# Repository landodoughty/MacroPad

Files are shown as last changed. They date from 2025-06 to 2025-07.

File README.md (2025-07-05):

# MacroPad
A Custom Macro Pad I Designed and Built based on the RP2040

# Features:
* Programmable keys allow shortcuts, macros, or controls to be customized.
* Hotswappable MX switches allows you to customize your typing feel.
* RGB Backlighting allows per-key lighting using WS2812/NeoPixel LEDs
* Custom 3d printed case provides a sleek, ergonomic look.

# Building the MacroPad

**The PCB:**
In this repository you can find the raw PCB files and the Gerber files which can allow you to manufacture the PCB through a service such as PCBWay or JLCPCB. I have also attached a BOM containing all the parts for the PCB. Most of the parts utilized on the PCB are very standard, and if you are assembling through JLCPCB the BOM already contains LCSC part numbers for most items. The only items which don't have part numbers, because I did not have them assembled through JLCPCB are the USB Micro-B connector, the reverse mount neopixel LEDs, the MX keyswitch sockets, and a small two pin 2.54mm pitch connector. The USB connector and the two pin connector can be easily bought from many places or even salvaged from old electronics. The [reverse mount LEDs]([url](https://www.adafruit.com/product/4960)) and [MX keyswitch sockets]([url](https://www.adafruit.com/product/4958)) are from adafruit. 

**Switches:**
You can use any MX compatible switches with the PCB, but keep in mind that they all have varying heights. The STLs provided are designed for switches with a 7mm above-board height with DSA keycaps, significantly less than most switches. If you want to use a different heigh you will likely have to adjust the STEP file provided to match your keyheight.

**Code:**
The code is provided but you will need to adjust it to fit your desires. This includes changing the LED modes and key press actions. Currently, the LED modes includes a constant color mode, an RGB mode, and a layer specific mode. To change layers, you press the first two buttons on the top row and then press the third button. To change colors in the constant color mode, you again press the first two buttons on the top row but then press the fourth button to change colors. To change the actions, scroll down to find the section where they are defined. The code shows how to do shortcuts, go to links, make a number pad, and how to create a shift key for a layer. To upload the code for the first time, short the two pins in the 2.54mm connector and then plug the MacroPad in through USB. It should pop up as detected and then yo ucan unshort the pins. Once you have done this once, you should be able to upload just with USB but if you are having issues uploading you may need to repeat the process.

**The Case:**
The case is 3d printed and I have provided both STL and STEP files for your conveinance. This means you can easily customize the case to your liking. The case needs 2 M3 heat set inserts, 2 M3 washers, and 2 M3 x 6 screws to assemble.

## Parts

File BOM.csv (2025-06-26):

Designator | Comment | Datasheet | Footprint | LCSC Part Number | Qty | DNP
C1,C2 | 15p | ~ | Capacitor_SMD:C_0603_1608Metric | C1644 | 2
C3,C4,C17 | 10u | ~ | Capacitor_SMD:C_0805_2012Metric | C15850 | 3
C5,C6,C7,C9,C11,C12,C13,C14,C15,C16 | 100n | ~ | Capacitor_SMD:C_0402_1005Metric | C1525 | 10
C8,C10 | 1u | ~ | Capacitor_SMD:C_0402_1005Metric | C52923 | 2
C21,C22,C23,C24,C25,C26,C27,C28,C29,C30,C31,C32,C33,C34,C35,C36,C37,C38,C39,C40 | 0.1u | ~ | Capacitor_SMD:C_0402_1005Metric | C1525 | 20
D1,D2,D3,D4,D5,D6,D7,D8,D9,D10,D11,D12,D13,D14,D15,D16,D17,D18,D19,D20 | NeoPixel_THT | https://www.adafruit.com/product/1938 | neoPixel:NEO3535_REVERSECorrected |  | 20
D21,D22,D23,D24,D25,D26,D27,D28,D29,D30,D31,D32,D33,D34,D35,D36,D37,D38,D39,D40 | 1N4148WS | https://www.vishay.com/docs/85751/1n4148ws.pdf | Diode_SMD:D_SOD-323 | C2128 | 20
H1,H2,H3,H4 | MountingHole | ~ | MountingHole:MountingHole_3.2mm_M3_ISO14580_Pad |  | 4
J1 | USB_B_Micro | ~ | Connector_USB:USB_Micro-B_Amphenol_10103594-0001LF_Horizontal | C10418 | 1
J2 | Conn_01x02 | ~ | Connector_PinHeader_2.54mm:PinHeader_1x02_P2.54mm_Vertical |  | 1
R1,R3 | 1k | ~ | Resistor_SMD:R_0402_1005Metric | C11702 | 2
R2 | DNF | ~ | Resistor_SMD:R_0402_1005Metric |  | 1
R4,R5 | 27 | ~ | Resistor_SMD:R_0402_1005Metric | C25100 | 2
SW1,SW2,SW3,SW4,SW5,SW6,SW7,SW8,SW9,SW10,SW11,SW12,SW13,SW14,SW15,SW16,SW17,SW18,SW19,SW20 | SW_SPST | ~ | keyswitches:Kailh_socket_MX |  | 20
U1 | AMS1117-3.3SOT223 | http://www.advanced-monolithic.com/pdf/ds1117.pdf | Package_TO_SOT_SMD:SOT-223 | C6186 | 1
U2 | W25Q128JVS | http://www.winbond.com/resource-files/w25q128jv_dtr%20revc%2003272018%20plus.pdf | Package_SO:SOIC-8_5.23x5.23mm_P1.27mm | C97521 | 1
U3 | RP2040 |  | Package_DFN_QFN:QFN-56-1EP_7x7mm_P0.4mm_EP3.2x3.2mm | C2040 | 1
U4 | 74AHCT1G125 | http://www.ti.com/lit/sg/scyt129e/scyt129e.pdf | Package_TO_SOT_SMD:SOT-23-5 | C7484 | 1
Y1 | ABM8-272-T3 | ~ | Crystal:Crystal_SMD_3225-4Pin_3.2x2.5mm | C20625731 | 1

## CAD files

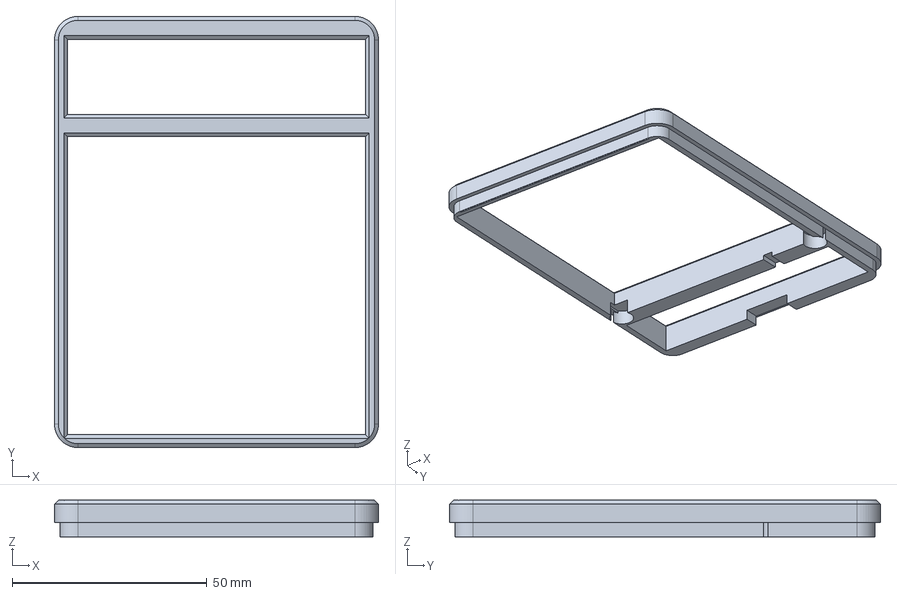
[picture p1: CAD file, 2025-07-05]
MacroPad - TopCover.step
83.2 x 110.7 x 9.40 mm

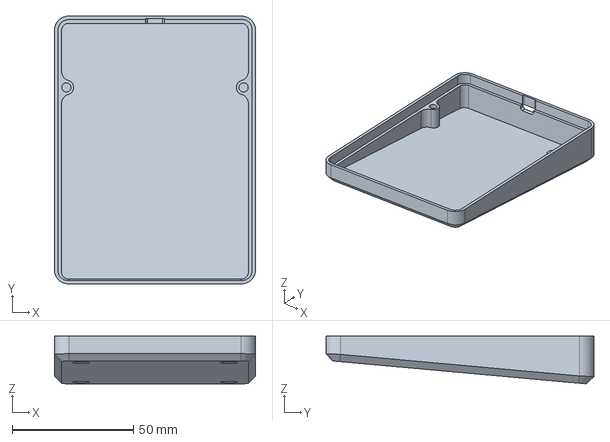
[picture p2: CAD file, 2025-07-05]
MacroPad - BottomShell.step
83.2 x 110.7 x 19.7 mm

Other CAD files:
MacroPad - BottomShell.stl
MacroPad - TopCover.stl

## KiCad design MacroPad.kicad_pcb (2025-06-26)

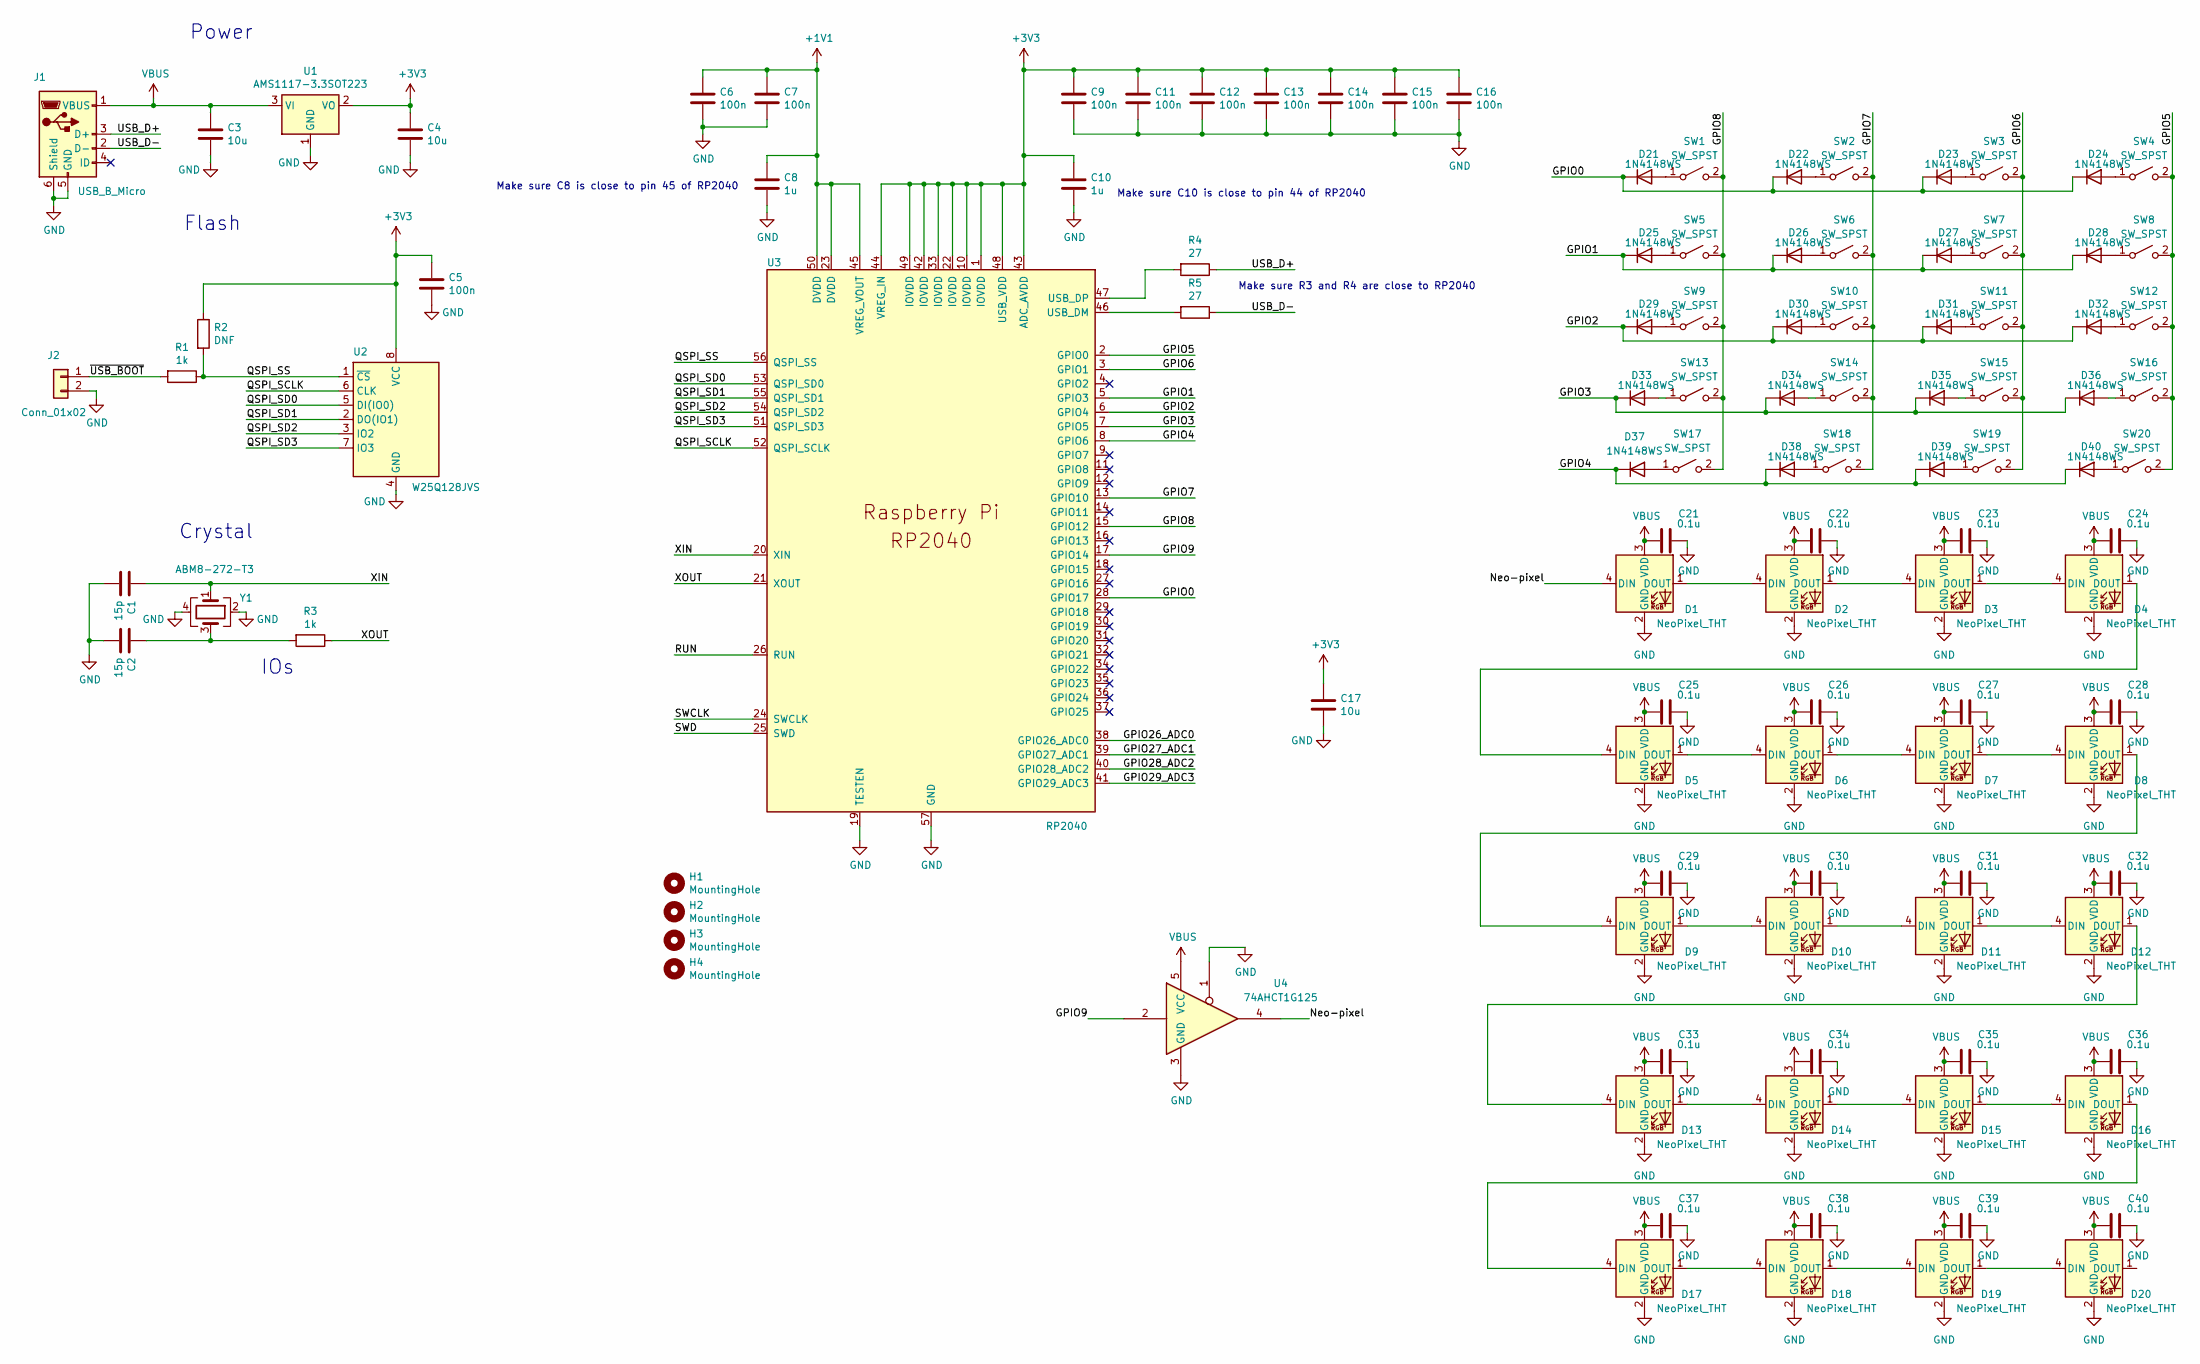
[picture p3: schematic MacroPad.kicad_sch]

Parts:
C1, C2: 15p; C_0603_1608Metric; LCSC Part Number C1644
C3, C4, C17: 10u; C_0805_2012Metric; LCSC Part Number C15850
C5, C6, C7, C9, C11, C12, C13, C14, C15, C16: 100n; C_0402_1005Metric; LCSC Part Number C1525
C8, C10: 1u; C_0402_1005Metric; LCSC Part Number C52923
C21, C22, C23, C24, C25, C26, C27, C28, C29, C30, C31, C32, C33, C34, C35, C36, C37, C38, C39, C40: 0.1u; C_0402_1005Metric; LCSC Part Number C1525
D1, D2, D3, D4, D5, D6, D7, D8, D9, D10, D11, D12, D13, D14, D15, D16, D17, D18, D19, D20: NeoPixel_THT; NEO3535_REVERSECorrected
D21, D22, D23, D24, D25, D26, D27, D28, D29, D30, D31, D32, D33, D34, D35, D36, D37, D38, D39, D40: 1N4148WS; D_SOD-323; LCSC Part Number C2128
H1, H2, H3, H4: MountingHole; MountingHole_3.2mm_M3_ISO14580_Pad
J1: USB_B_Micro; USB_Micro-B_Amphenol_10103594-0001LF_Horizontal; LCSC Part Number C10418
J2: Conn_01x02; PinHeader_1x02_P2.54mm_Vertical
R1, R3: 1k; R_0402_1005Metric; LCSC Part Number C11702
R2: DNF; R_0402_1005Metric
R4, R5: 27; R_0402_1005Metric; LCSC Part Number C25100
SW1, SW2, SW3, SW4, SW5, SW6, SW7, SW8, SW9, SW10, SW11, SW12, SW13, SW14, SW15, SW16, SW17, SW18, SW19, SW20: SW_SPST; Kailh_socket_MX
U1: AMS1117-3.3SOT223; SOT-223; LCSC Part Number C6186
U2: W25Q128JVS; SOIC-8_5.23x5.23mm_P1.27mm; LCSC Part Number C97521
U3: RP2040; QFN-56-1EP_7x7mm_P0.4mm_EP3.2x3.2mm; LCSC Part Number C2040
U4: 74AHCT1G125; SOT-23-5; LCSC Part Number C7484
Y1: ABM8-272-T3; Crystal_SMD_3225-4Pin_3.2x2.5mm; LCSC Part Number C20625731

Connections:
+1V1: C6.1, C7.1, C8.1, U3.23 (DVDD), U3.45 (VREG_VOUT), U3.50 (DVDD)
+3V3: C4.1, C5.1, C9.1, C10.1, C11.1, C12.1, C13.1, C14.1, C15.1, C16.1, C17.1, R2.1, U1.2 (VO), U2.8 (VCC), U3.1 (IOVDD), U3.10 (IOVDD), U3.22 (IOVDD), U3.33 (IOVDD), U3.42 (IOVDD), U3.43 (ADC_AVDD), U3.44 (VREG_IN), U3.48 (USB_VDD), U3.49 (IOVDD)
/GPIO0: D21.1 (K), D22.1 (K), D23.1 (K), D24.1 (K), U3.28 (GPIO17)
/GPIO1: D25.1 (K), D26.1 (K), D27.1 (K), D28.1 (K), U3.5 (GPIO3)
/GPIO2: D29.1 (K), D30.1 (K), D31.1 (K), D32.1 (K), U3.6 (GPIO4)
/GPIO3: D33.1 (K), D34.1 (K), D35.1 (K), D36.1 (K), U3.7 (GPIO5)
/GPIO4: D37.1 (K), D38.1 (K), D39.1 (K), D40.1 (K), U3.8 (GPIO6)
/GPIO5: SW4.2 (B), SW8.2 (B), SW12.2 (B), SW16.2 (B), SW20.2 (B), U3.2 (GPIO0)
/GPIO6: SW3.2 (B), SW7.2 (B), SW11.2 (B), SW15.2 (B), SW19.2 (B), U3.3 (GPIO1)
/GPIO7: SW2.2 (B), SW6.2 (B), SW10.2 (B), SW14.2 (B), SW18.2 (B), U3.13 (GPIO10)
/GPIO8: SW1.2 (B), SW5.2 (B), SW9.2 (B), SW13.2 (B), SW17.2 (B), U3.15 (GPIO12)
/GPIO9: U3.17 (GPIO14), U4.2
/GPIO26_ADC0: U3.38 (GPIO26_ADC0)
/GPIO27_ADC1: U3.39 (GPIO27_ADC1)
/GPIO28_ADC2: U3.40 (GPIO28_ADC2)
/GPIO29_ADC3: U3.41 (GPIO29_ADC3)
/Neo-pixel: D1.4 (DIN), U4.4
/QSPI_SCLK: U2.6 (CLK), U3.52 (QSPI_SCLK)
/QSPI_SD0: U2.5 (DI(IO0)), U3.53 (QSPI_SD0)
/QSPI_SD1: U2.2 (DO(IO1)), U3.55 (QSPI_SD1)
/QSPI_SD2: U2.3 (IO2), U3.54 (QSPI_SD2)
/QSPI_SD3: U2.7 (IO3), U3.51 (QSPI_SD3)
/QSPI_SS: R1.1, R2.2, U2.1 (~CS), U3.56 (QSPI_SS)
/RUN: U3.26 (RUN)
/SWCLK: U3.24 (SWCLK)
/SWD: U3.25 (SWD)
/USB_D+: J1.3 (D+), R4.1
/USB_D-: J1.2 (D-), R5.1
/XIN: C1.1, U3.20 (XIN), Y1.1
/XOUT: R3.1, U3.21 (XOUT)
/~USB_BOOT: J2.1, R1.2
GND: C1.2, C2.2, C3.2, C4.2, C5.2, C6.2, C7.2, C8.2, C9.2, C10.2, C11.2, C12.2, C13.2, C14.2, C15.2, C16.2, C17.2, C21.2, C22.2, C23.2, C24.2, C25.2, C26.2, C27.2, C28.2, C29.2, C30.2, C31.2, C32.2, C33.2, C34.2, C35.2, C36.2, C37.2, C38.2, C39.2, C40.2, D1.2 (GND), D2.2 (GND), D3.2 (GND), D4.2 (GND), D5.2 (GND), D6.2 (GND), D7.2 (GND), D8.2 (GND), D9.2 (GND), D10.2 (GND), D11.2 (GND), D12.2 (GND), D13.2 (GND), D14.2 (GND), D15.2 (GND), D16.2 (GND), D17.2 (GND), D18.2 (GND), D19.2 (GND), D20.2 (GND), J1.5 (GND), J1.6 (Shield), J2.2, U1.1 (GND), U2.4 (GND), U3.19 (TESTEN), U3.57 (GND), U4.1, U4.3 (GND), Y1.2, Y1.4
unnamed: C2.1, R3.2, Y1.3
unnamed: D1.1 (DOUT), D2.4 (DIN)
unnamed: D2.1 (DOUT), D3.4 (DIN)
unnamed: D3.1 (DOUT), D4.4 (DIN)
unnamed: D4.1 (DOUT), D5.4 (DIN)
unnamed: D5.1 (DOUT), D6.4 (DIN)
unnamed: D6.1 (DOUT), D7.4 (DIN)
unnamed: D7.1 (DOUT), D8.4 (DIN)
unnamed: D8.1 (DOUT), D9.4 (DIN)
unnamed: D9.1 (DOUT), D10.4 (DIN)
unnamed: D10.1 (DOUT), D11.4 (DIN)
unnamed: D11.1 (DOUT), D12.4 (DIN)
unnamed: D12.1 (DOUT), D13.4 (DIN)
unnamed: D13.1 (DOUT), D14.4 (DIN)
unnamed: D14.1 (DOUT), D15.4 (DIN)
unnamed: D15.1 (DOUT), D16.4 (DIN)
unnamed: D16.1 (DOUT), D17.4 (DIN)
unnamed: D17.1 (DOUT), D18.4 (DIN)
unnamed: D18.1 (DOUT), D19.4 (DIN)
unnamed: D19.1 (DOUT), D20.4 (DIN)
unnamed: D21.2 (A), SW1.1 (A)
unnamed: D22.2 (A), SW2.1 (A)
unnamed: D23.2 (A), SW3.1 (A)
unnamed: D24.2 (A), SW4.1 (A)
unnamed: D25.2 (A), SW5.1 (A)
unnamed: D26.2 (A), SW6.1 (A)
unnamed: D27.2 (A), SW7.1 (A)
unnamed: D28.2 (A), SW8.1 (A)
unnamed: D29.2 (A), SW9.1 (A)
unnamed: D30.2 (A), SW10.1 (A)
unnamed: D31.2 (A), SW11.1 (A)
unnamed: D32.2 (A), SW12.1 (A)
unnamed: D33.2 (A), SW13.1 (A)
unnamed: D34.2 (A), SW14.1 (A)
unnamed: D35.2 (A), SW15.1 (A)
unnamed: D36.2 (A), SW16.1 (A)
unnamed: D37.2 (A), SW17.1 (A)
unnamed: D38.2 (A), SW18.1 (A)
unnamed: D39.2 (A), SW19.1 (A)
unnamed: D40.2 (A), SW20.1 (A)
unnamed: R5.2, U3.46 (USB_DM)
unnamed: R4.2, U3.47 (USB_DP)
VBUS: C3.1, C21.1, C22.1, C23.1, C24.1, C25.1, C26.1, C27.1, C28.1, C29.1, C30.1, C31.1, C32.1, C33.1, C35.1, C36.1, C37.1, C38.1, C39.1, C40.1, D1.3 (VDD), D2.3 (VDD), D3.3 (VDD), D4.3 (VDD), D5.3 (VDD), D6.3 (VDD), D7.3 (VDD), D8.3 (VDD), D9.3 (VDD), D10.3 (VDD), D11.3 (VDD), D12.3 (VDD), D13.3 (VDD), D14.3 (VDD), D15.3 (VDD), D16.3 (VDD), D17.3 (VDD), D18.3 (VDD), D19.3 (VDD), D20.3 (VDD), J1.1 (VBUS), U1.3 (VI), U4.5 (VCC)

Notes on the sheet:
IOs
Make sure R3 and R4 are close to RP2040
Make sure C10 is close to pin 44 of RP2040
Make sure C8 is close to pin 45 of RP2040
Power
Crystal
Flash

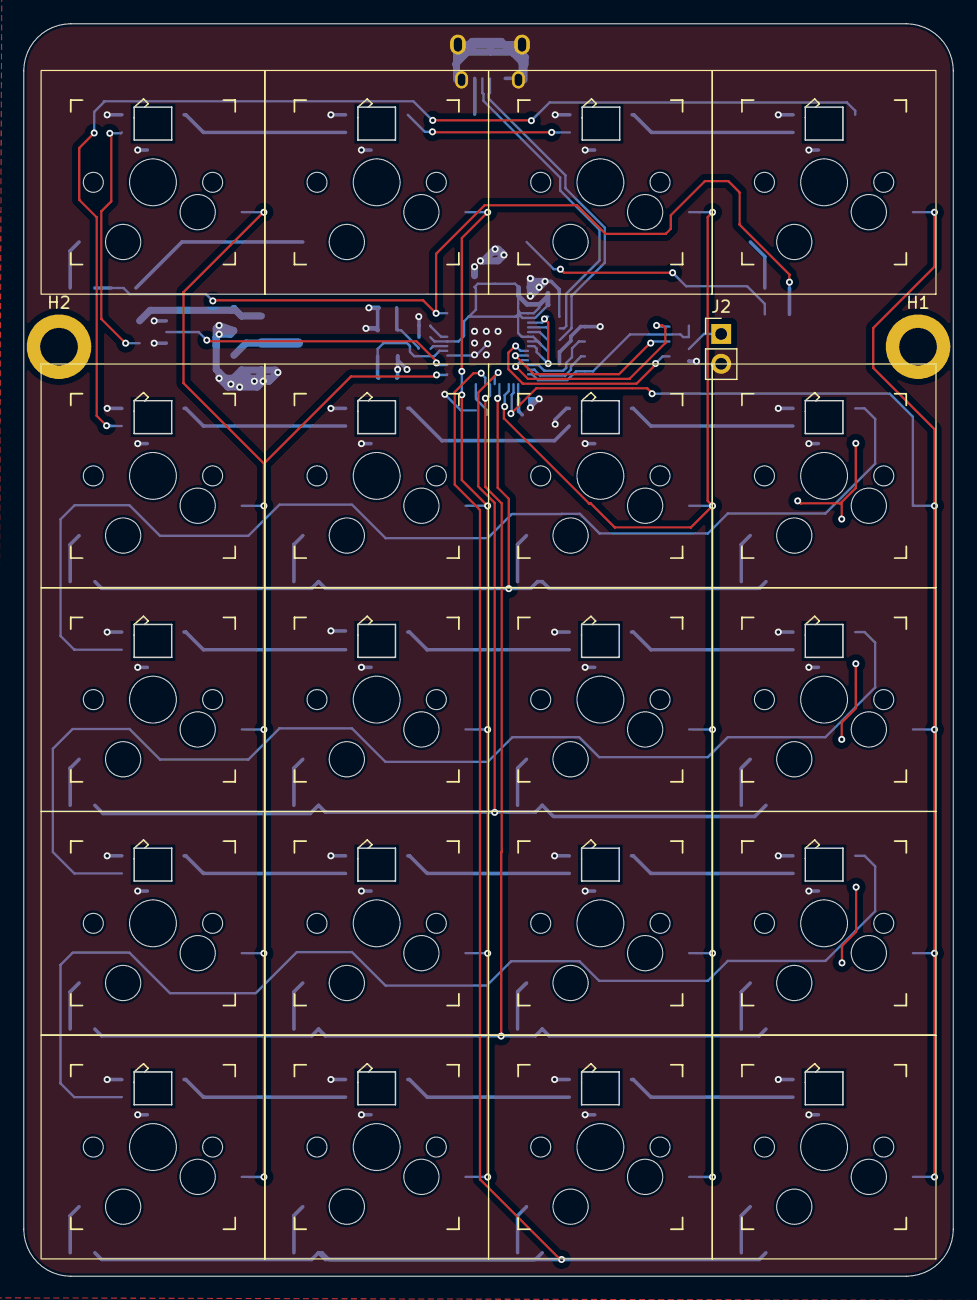
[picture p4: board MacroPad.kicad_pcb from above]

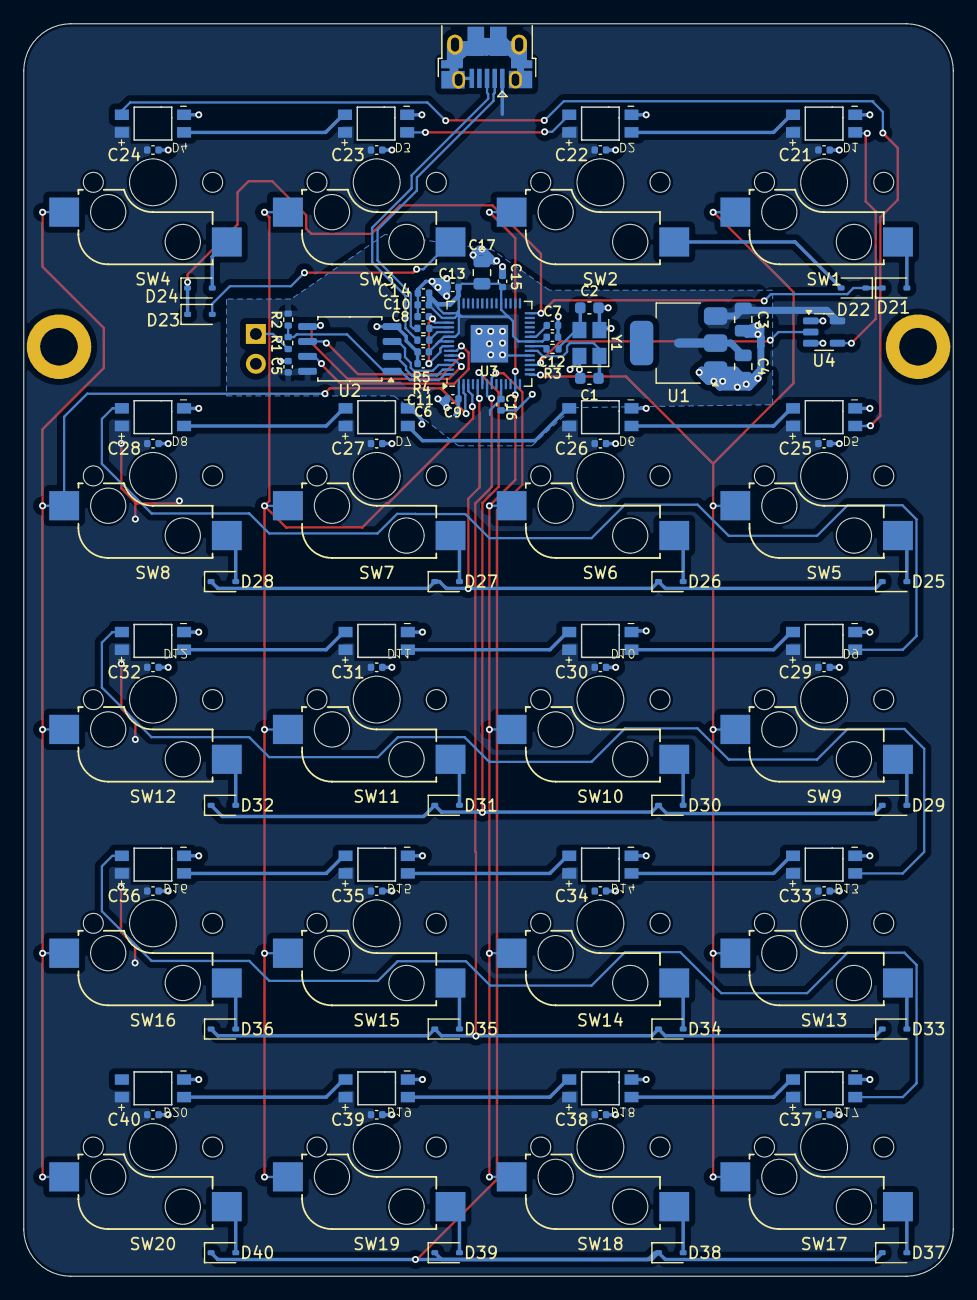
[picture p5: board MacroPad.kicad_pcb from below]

Board: 2 copper layers, 79.2 x 106.7 mm, 111 parts (68 on the bottom side), 68 nets.

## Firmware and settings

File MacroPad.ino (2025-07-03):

#include <Keyboard.h>;
#include <Adafruit_NeoPixel.h>
#ifdef __AVR__
#include <avr/power.h>
#endif

void checkForPress(int x, int y, char key1, char key2 = '\0', char key3 = '\0');//prototype function for optional arguments

//ctrl and shift keys THESE NEED TO BE CHANGED BASED ON YOUR DESIRED OPERATING SYSTEM
char ctrlKey = KEY_LEFT_CTRL;
char shiftKey = KEY_LEFT_SHIFT;
char altKey = KEY_LEFT_ALT;

//define neopixels
int neoPixelPin = 14;
Adafruit_NeoPixel pixels(20, neoPixelPin, NEO_GRB + NEO_KHZ800);

//The following are the collumn and row numbers for writing and reading the keys
int c1 = 12;
int c2 = 10;
int c3 = 1;
int c4 = 0;
int r1 = 17;
int r2 = 3;
int r3 = 4;
int r4 = 5;
int r5 = 6;

//arrays for pins and holding values
int cols[] = {c1, c2, c3, c4};
int rows[] = {r1, r2, r3, r4, r5};
int vals[4][5];
int prev[4][5];


int ledMode = 2; // mode 0 is constant color which can be switched, mode 1 is rgb, mode 2 is by layer
int ledValSelector = 0; //this changes between solid colors
long ledModeSwitchCooldown = 0;//these two cooldowns makes sure it doesnt switch through led modes too quickly
long ledValSelectorCooldown = 0;
int r = 255;//rgb values to cycle
int g = 0;
int b = 0;
int rgbToChange = 2;//helper variable for rgb cycle
long prevLedChange = 0;//helper variable for slowing rgb cycle

int layer = 1; //currently: 0->num pad 1->links and macros
int numPadLeds[20] = {0, 0, 0, 0, 1, 1, 1, 0, 1, 1, 1, 0, 1, 1, 1, 0, 0, 1, 0, 0};
int partStudioLeds[20][3] = { {0, 0, 0}, {0, 0, 0}, {0, 0, 0}, {0, 0, 0},
  {0, 0, 255}, {255, 0, 0}, {255, 0, 0}, {255, 0, 0},
  {0, 0, 255}, {255, 200, 0}, {255, 200, 0}, {0, 255, 0},
  {255, 60, 0}, {255, 60, 0}, {0, 255, 255}, {0, 255, 0},
  {0, 0, 0}, {255, 0, 255}, {255, 0, 255}, {0, 0, 0}
};


//settings
long keypressCooldown = 200;//use this variable to set limit on how fast you can change RGB modes
long ledChangeDelay = 5;//use this variable to change how fast RGB cycle goes
int ledVals[9][3] = {{255, 255, 255}, {255, 0, 0}, {255, 60, 0}, {255, 200, 0}, {0, 255, 0}, {0, 255, 255}, {0, 0, 255}, {255, 0, 255}, {0, 0, 0}};
//^ these are the solid colors you can cycle through. If you want to change the number of colors make sure to change the number in the initialization of ledVals and the modulus number in the detection for led color change block of code in loop


// the setup function runs once when you press reset or power the board
void setup() {
  //set collumns to output and rows to input pulled low
  pinMode(c1, OUTPUT);
  pinMode(c2, OUTPUT);
  pinMode(c3, OUTPUT);
  pinMode(c4, OUTPUT);
  pinMode(r1, INPUT_PULLDOWN);
  pinMode(r2, INPUT_PULLDOWN);
  pinMode(r3, INPUT_PULLDOWN);
  pinMode(r4, INPUT_PULLDOWN);
  pinMode(r5, INPUT_PULLDOWN);

  Serial.begin(9600);
  Keyboard.begin();
  pixels.begin();
  //doing this will disable all the columns.
  digitalWrite(c1, LOW);
  digitalWrite(c2, LOW);
  digitalWrite(c3, LOW);
  digitalWrite(c4, LOW);

}

void checkForPress(int x, int y, char key1, char key2 , char key3) {
  if (vals[x][y] == 1 && prev[x][y] == 0) {
    Keyboard.press(key3);
    Keyboard.press(key2);
    Keyboard.press(key1);
  } else if (vals[x][y] == 0 && prev[x][y] == 1) {
    Keyboard.release(key1);
    Keyboard.release(key2);
    Keyboard.release(key3);
  }
  prev[x][y] = vals[x][y];
}
void checkForPressToLink(int x, int y, String link) {
  if (vals[x][y] == 1 && prev[x][y] == 0) {
    Keyboard.press(ctrlKey);
    Keyboard.press('t');
    delay(2);
    Keyboard.release(ctrlKey);
    Keyboard.release('t');
    delay(2);
    Keyboard.print(link);
    Keyboard.press('\n');
    Keyboard.release('\n');
  }
  prev[x][y] = vals[x][y];
}


void updateLEDs() {
  //led mode 0: constant color for all keys
  if (ledMode == 0) {
    pixels.clear();
    for (int j = 0; j < 20; j++) {
      pixels.setPixelColor(j, pixels.Color(ledVals[ledValSelector][0], ledVals[ledValSelector][1], ledVals[ledValSelector][2]));
    }
  }
  //led mode 1: rgb
  else if (ledMode == 1 && (prevLedChange + ledChangeDelay < millis()) ) {
    prevLedChange = millis();
    pixels.clear();

    switch (rgbToChange) {
      case 1:
        r++;
        if (r == 255) rgbToChange = -3;
        break;
      case 2:
        g++;
        if (g == 255) rgbToChange = -1;
        break;
      case 3:
        b++;
        if (b == 255) rgbToChange = -2;
        break;
      case -1:
        r--;
        if (r == 0) rgbToChange = 3;
        break;
      case -2:
        g--;
        if (g == 0) rgbToChange = 1;
        break;
      case -3:
        b--;
        if (b == 0) rgbToChange = 2;
        break;
    }

    for (int j = 0; j < 20; j++) {
      pixels.setPixelColor(j, pixels.Color(r, g, b));
    }

  //led mode 2 changes based on current layer:
  } else if (ledMode == 2) {
    pixels.clear();
    if (layer == 0 ) {
      for (int j = 0; j < 20; j++) {
        pixels.setPixelColor(j, pixels.Color(ledVals[ledValSelector][0]*numPadLeds[j], ledVals[ledValSelector][1]*numPadLeds[j], ledVals[ledValSelector][2]*numPadLeds[j]));
      }
    } else if (layer == 1) {
      for (int j = 0; j < 20; j++) {
        pixels.setPixelColor(j, pixels.Color(ledVals[ledValSelector][0], ledVals[ledValSelector][1], ledVals[ledValSelector][2]));
      }

    } else {
      for (int j = 0; j < 20; j++) {
        pixels.setPixelColor(j, pixels.Color(partStudioLeds[j][0], partStudioLeds[j][1], partStudioLeds[j][2]));
      }

    }
  }

  pixels.show();

}

// the loop function runs over and over again forever
void loop() {
  updateLEDs();

  //loop through array of keys and read
  for (int i = 0; i < 4; i++) {
    digitalWrite(cols[i], HIGH);
    for (int j = 0; j < 5; j++) {
      vals[i][j] = digitalRead(rows[j]);
    }
    digitalWrite(cols[i], LOW);
  }


  //detection for led mode change
  if (vals[0][0] == 1 && vals[1][0] == 1 && vals[2][0] == 1) {
    vals[0][0] = 0;
    vals[1][0] = 0;
    vals[2][0] = 0;
    if (ledModeSwitchCooldown + keypressCooldown < millis()) {
      ledMode++;
      ledMode = ledMode % 3; // this number is the total number of mode options
      ledModeSwitchCooldown = millis();
    }
  }

  //detection for led color change
  if (vals[0][0] == 1 && vals[1][0] == 1 && vals[3][0] == 1) {
    vals[0][0] = 0;
    vals[1][0] = 0;
    vals[3][0] = 0;
    if (ledValSelectorCooldown + keypressCooldown < millis()) {
      ledValSelector++;
      ledValSelector = ledValSelector % 9; // this number is the total number of mode options
      ledValSelectorCooldown = millis();
    }
  }

  if (vals[0][0] == 1 && vals[1][0] == 1) {
    vals[0][0] = 0;
    vals[1][0] = 0;
  }
  
  //check for layer change
  if (vals[2][0] == 1 && prev[2][0] == 0) {
    layer += 1;
    layer = layer % 2;
  }
  prev[2][0] = vals[2][0];



  if (layer == 0) { //example of using layer 0 as a number pad
    //always active
    checkForPress(3, 0, '\b');
    checkForPress(0, 0, '\x1B');
    checkForPress(3, 4, '\n');
    checkForPress(0, 1, '7');
    checkForPress(1, 1, '8');
    checkForPress(2, 1, '9');
    checkForPress(0, 2, '4');
    checkForPress(1, 2, '5');
    checkForPress(2, 2, '6');
    checkForPress(0, 3, '1');
    checkForPress(1, 3, '2');
    checkForPress(2, 3, '3');
    checkForPress(1, 4, '0');
    checkForPress(2, 4, '.');

    if (vals[0][4] == 0) { //non shift
      checkForPress(3, 1, '(');
      checkForPress(3, 2, '*');
      checkForPress(3, 3, '+');
    } else { //shift
      checkForPress(3, 1, ')');
      checkForPress(3, 2, '/');
      checkForPress(3, 3, '-');
    }
  } else if (layer == 1) {//this is an example of using the bottom layer for opening links in chrome
    checkForPressToLink(0, 1, "https://chatgpt.com/?model=auto");
    checkForPressToLink(1, 1, "https://www.youtube.com/");
    checkForPressToLink(2, 1, "https://www.linkedin.com/feed/");
    checkForPressToLink(3, 1, "https://www.amazon.com/");
    checkForPressToLink(0, 2, "https://www.printables.com/model?period=year");
    checkForPressToLink(1, 2, "https://cad.onshape.com/documents?nodeId=0&resourceType=filter");
    checkForPressToLink(2, 2, "https://github.com/landodoughty");
    checkForPressToLink(3, 2, "https://landodoughty.github.io/index.html");
    checkForPressToLink(0, 3, "https://mail.google.com/mail/u/0/#inbox");
    checkForPressToLink(1, 3, "https://mail.google.com/mail/u/4/#inbox");
    checkForPressToLink(2, 3, "https://docs.google.com/document/u/4/?tgif=d");
    //    checkForPressToLink(3,3,"htt");
    checkForPressToLink(0, 4, "https://idp.rice.edu/idp/profile/cas/login?execution=e1ps://www.youtube.com/s1");
    checkForPressToLink(1, 4, "https://canvas.rice.edu/");
    checkForPress(2, 4, 'c', ctrlKey);
    checkForPress(3, 4, 'p', ctrlKey);//example of doing commands
  }

}


//onshape part studio shortcuts:
/*
   if (vals[0][4] == 0) { //non shift
      checkForPress(0, 1, 's', shiftKey); //sketch
      checkForPress(1, 1, 'e', shiftKey); //extrude
      checkForPress(2, 1, 'w', shiftKey); //revolve
      checkForPress(3, 1, 'f', shiftKey); //filet
      checkForPress(0, 2, 'n');//view normal
      checkForPress(1, 2, 'm', shiftKey, altKey); //mirror
      checkForPress(2, 2, 's', shiftKey, altKey); //shell
      checkForPress(3, 2, 'l', shiftKey, altKey); //linear pattern
      checkForPress(0, 3, 't', ctrlKey, altKey); //transform
      checkForPress(1, 3, 'm', ctrlKey, altKey); //move face
      checkForPress(2, 3, 'i');//derived/insert
      checkForPress(3, 3, 'h', ctrlKey, altKey); //helix
      checkForPress(1, 4, 'm');//mate
      checkForPress(2, 4, 'r', ctrlKey, altKey); //mate relation

    } else { //shift
      checkForPress(0, 1, 'p', shiftKey, altKey); //new plane
      checkForPress(1, 1, 'l', ctrlKey, altKey); //loft
      checkForPress(2, 1, 'w', ctrlKey, altKey); //sweep
      checkForPress(3, 1, 'c');//chamfer
      checkForPress(0, 2, 'p');//show/hide planes
      checkForPress(1, 2, 'b', ctrlKey, altKey); //boolean
      checkForPress(2, 2, 's', ctrlKey, altKey); //split
      checkForPress(3, 2, 'o');//circular pattern
      checkForPress(0, 3, 't', ctrlKey, altKey); //transform
      checkForPress(1, 3, 'f', ctrlKey, altKey); //replace face

      checkForPress(2, 3, 'v');//variable
      checkForPress(3, 3, 'p', ctrlKey, altKey); //curvePattern
      checkForPress(1, 4, 'r');//replicate
      checkForPress(2, 4, 'j');//hide/show mates
    }
*/

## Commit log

2025-06-26 Custom PCB files
    BOM and CSV adjusted for JLCPCB assembly
    [BOM.csv, MacroPad.kicad_pcb, MacroPad.kicad_sch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]
2025-07-03 CAD Files
    [MacroPad - BottomShell.stl, MacroPad - TopCover.stl]
2025-07-05 STEP Files
    [MacroPad - BottomShell.step, MacroPad - TopCover.step]
